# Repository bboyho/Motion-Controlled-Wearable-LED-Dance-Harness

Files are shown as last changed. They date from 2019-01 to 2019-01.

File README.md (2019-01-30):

Motion Controlled Wearable LED Dance Harness
-------------------

This code will be used to control the 12V LED strips attached to a dancer's custom harness. Each harness is controlled using an n-channel MOSFET, an accelerometer, and an Arduino Pro Mini for a performance with Streetside Studio's bboys/bgirls.

<table class="table table-hover table-striped table-bordered">
  <tr align="center">
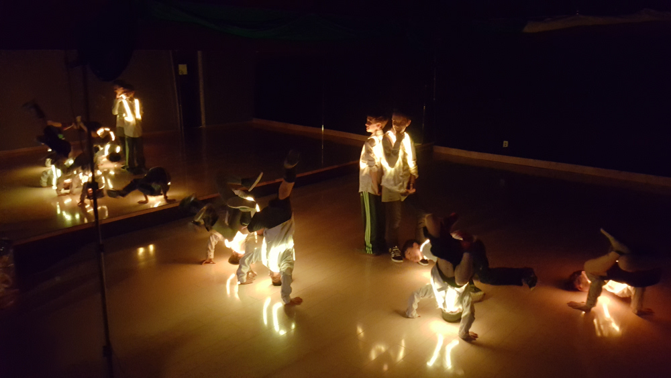
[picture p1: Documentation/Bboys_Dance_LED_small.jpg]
Bboys Freezed
    <td></td>
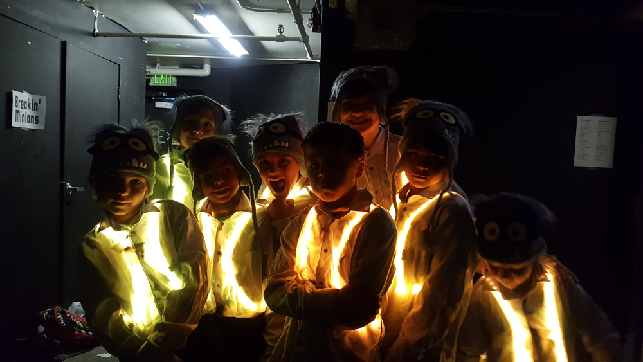
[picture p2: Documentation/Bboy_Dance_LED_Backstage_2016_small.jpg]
Bboys w/ Motion Controlled Wearable LED Dance Harness
    <td></td>
  </tr>
  <tr align="center">
    <td><a href="https://www.instagram.com/p/BExpFgNOczp/">Instagram: bobbybrownrice Demo Image</a></td>
    <td><a href="https://www.instagram.com/p/BFav-Fbucyi/">Instagram: bobbybrownrice Demo Video</a></td>
  </tr>
</table>

For more information about building the harness, check out the tutorials linked below!

Repository Contents
-------------------
* **/Documentation** - Images, Circuit, Fritzing Diagrams
* **/Firmware/Arduino** - Example code 
  * _MinionAccelerometerV2.0_ - Test code for 1 dancer.
  * _MinionAccelerometerV2.1_ - Code calibrated for all 8 dancers.

Documentation
--------------
* Project Tutorial
  * **[Prototype Wearable LED Dance Harness](https://learn.sparkfun.com/tutorials/prototype-wearable-led-dance-harness)** - Project guide to make Mark II of the prototype wearable LED dance harness.
  * **[Motion Controlled Wearable LED Dance Harness](https://learn.sparkfun.com/tutorials/motion-controlled-wearable-led-dance-harness/all)** - Project guide to make Mark III of the wearable LED dance harness. The only difference is that Mark III uses an N-channel MOSFET, accelerometer, and an Arduino Pro Mini to control the colors.
* **[Instagram: bobbybrownrice Demo Video](https://www.instagram.com/p/BExpFgNOczp/)** - Mark III in action.
* **[Instagram: bobbybrownrice Demo Image](https://www.instagram.com/p/BExpFgNOczp/)** - Mark III demo image.

License Information
-------------------

This project is _**open source**_! 

Please review the [LICENSE.md file](https://github.com/bboyho/ledStrap/blob/master/LICENSE.md) for license information. 

Distributed as-is; no warranty is given.

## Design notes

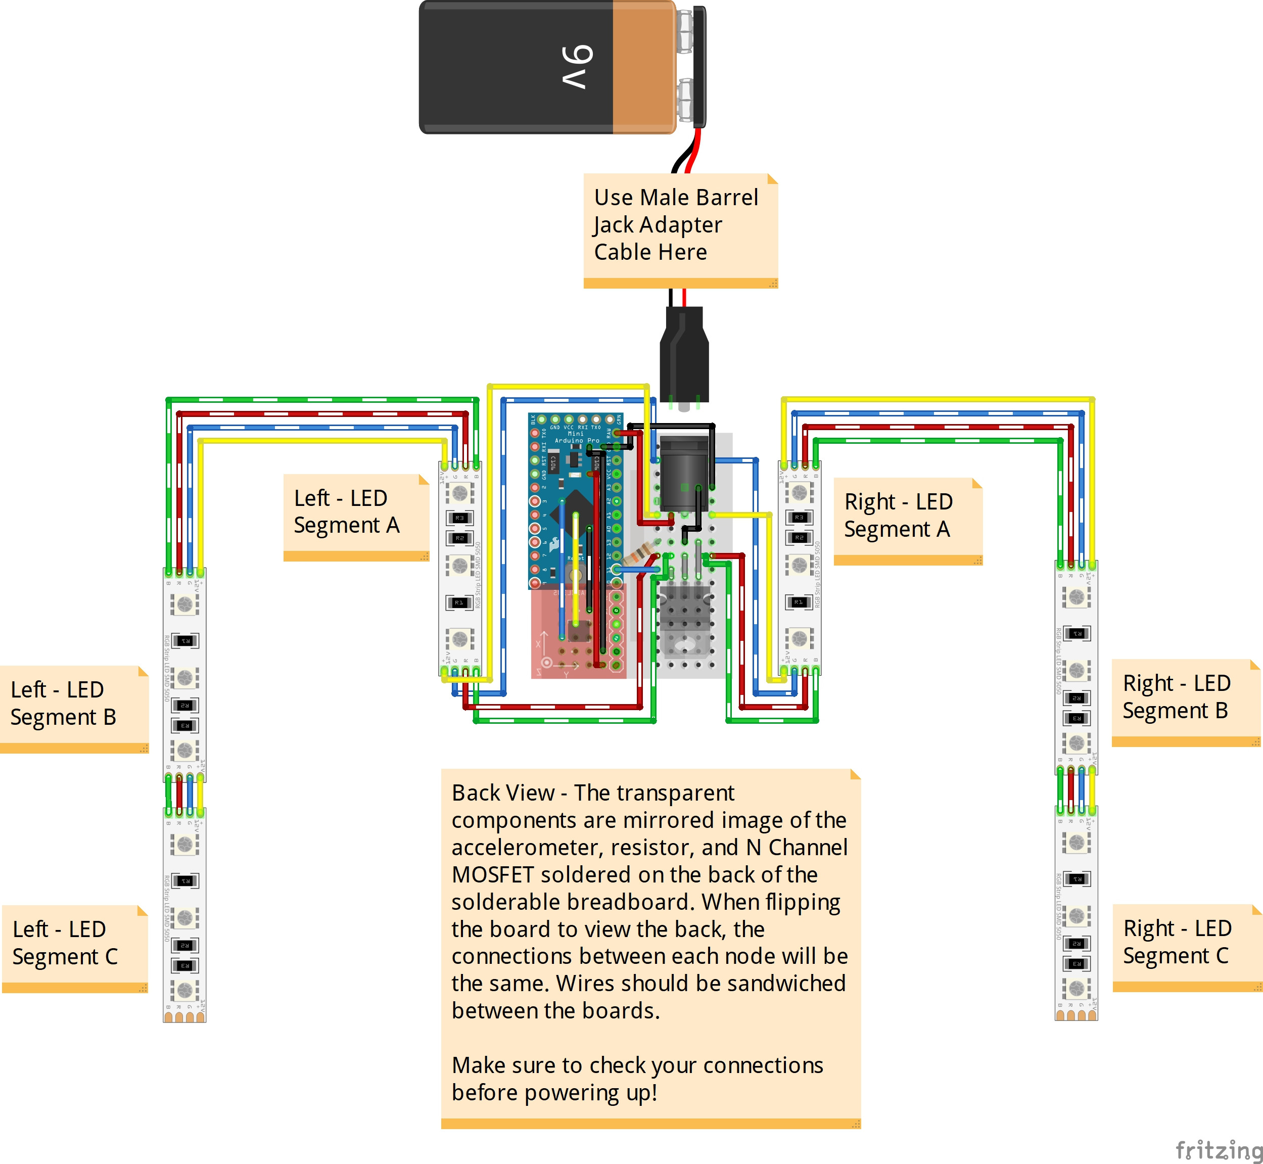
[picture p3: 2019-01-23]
Documentation/SparkFun_MotionControlledWearableLEDDanceHarnessCircuitComplete_Fritzing_Back_View_bb_1.jpg

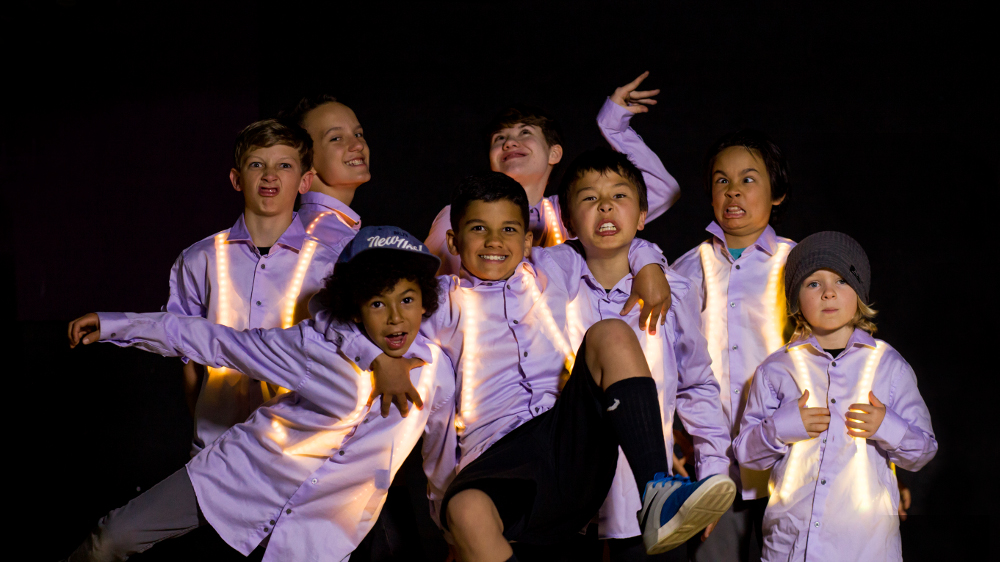
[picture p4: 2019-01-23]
Documentation/BBoys_LED_Harness_Dance_small.jpg

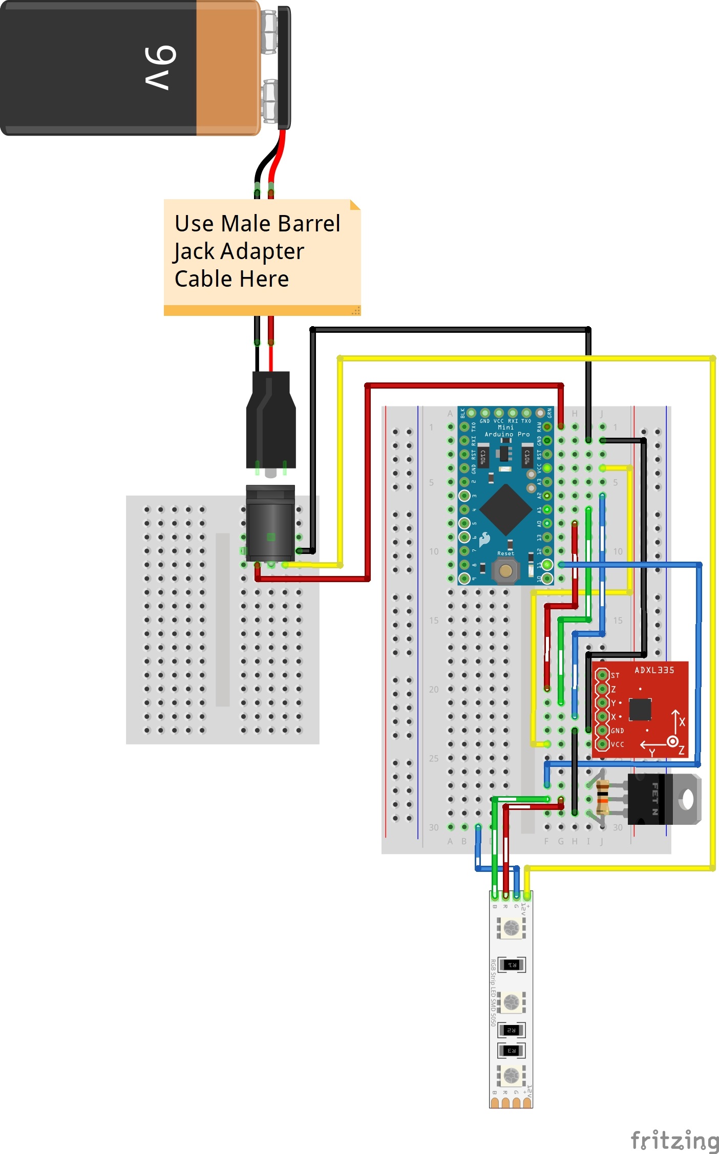
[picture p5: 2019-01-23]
Documentation/SparkFun_MotionControlledWearableLEDDanceHarnessCircuit_Fritzing_bb.jpg

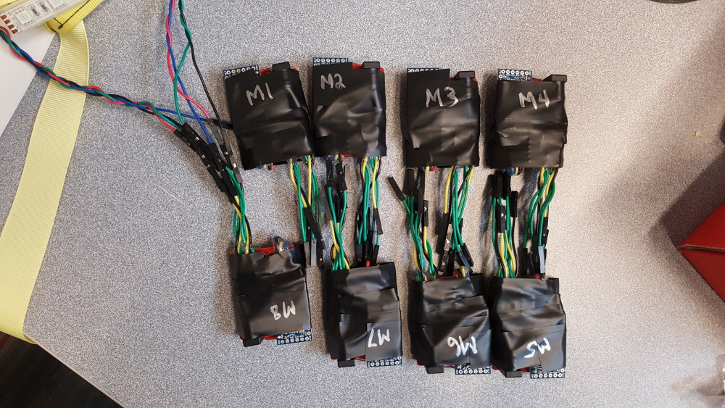
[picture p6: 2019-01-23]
Documentation/Arduino LED Motion Controller_small.jpg

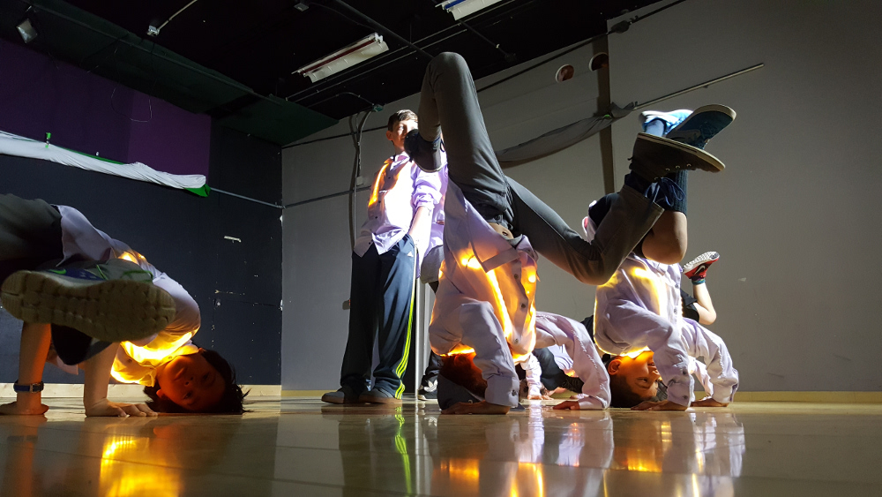
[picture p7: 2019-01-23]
Documentation/Bboys_Dance_LED_Freezes_small.jpg

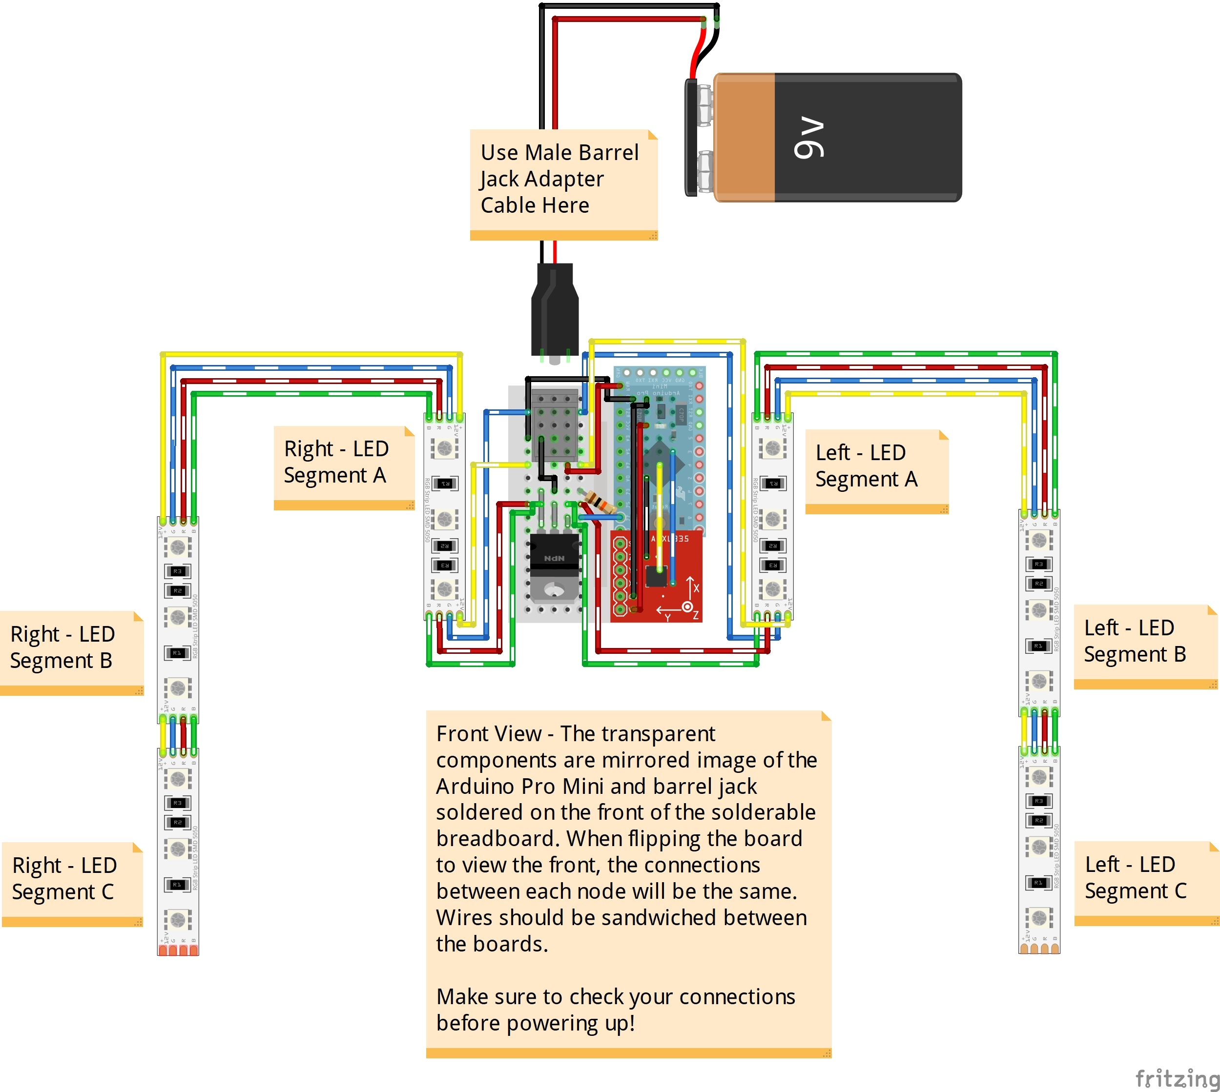
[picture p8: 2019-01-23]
Documentation/SparkFun_MotionControlledWearableLEDDanceHarnessCircuitComplete_Fritzing_Front_View_bb.jpg

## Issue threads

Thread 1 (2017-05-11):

Error in Calibration v2.1

bboyho, 2017-05-11:
There is a problem with the code in the calibration. The condition statement should use a "==" sign.

bboyho, 2019-01-25:
Fixed.

Closed 2019-01-25.

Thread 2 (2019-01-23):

Insert Delay in v2.0

bboyho, 2019-01-23:
Insert delay to slow down reading for manual calibration:

      Serial.println("");
      delay(500);

bboyho, 2019-02-06:
added but commented out the delat in code

Closed 2019-02-06.

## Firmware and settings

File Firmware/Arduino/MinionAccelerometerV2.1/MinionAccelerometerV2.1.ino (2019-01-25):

//MinionAccelerometer.ino
//v2.1
//By: Ho Yun "Bobby" Chan (Worm Tank Crew, Block 1750)
//May 13, 2016
//Sparkfun Electronis Inc.

/*Description: This code will be used to control the 12V LED strips
attached to a dancer's custom strap using an n-channel MOSFET for a
performance with Streetside Studio's bboys/bgirls.

Values calibrated using Earth's gravity when accelerometer at rest.
Depending on what accelerometer is used, change the global variable
calibration_M and calibrationADXL335() for that specific accelerometer.

-------Accelerometer Mode = 1 -------
Features
1.) xAxis
Standing = LED on
Upside down = LED Blinking

2.) yAxis
On the left or right side= LED off

3.) zAxis
On stomach or back = LED fading */

//Code Inspired By:
//bildr ADXL335Example, by Adam Meyer and bildr.org Team
//[ http://bildr.org/2011/04/sensing-orientation-with-the-adxl335-arduino/ ]
//[ http://bildr.org/2012/03/rfp30n06le-arduino/ ]
//Arduino Fade Example, by David A. Mellis and Tom Igoe
//[ http://www.arduino.cc/en/Tutorial/Fading ]

//set analog read pins
const int xPin = 2;//x=A2
const int yPin = 1;//y=A1
const int zPin = 0;//z=A0

//read the analog values from the accelerometer
int xRead = analogRead(xPin);
int yRead = analogRead(yPin);
int zRead = analogRead(zPin);

//Calibration
int calibration_M = 8; //this is used to calibrate the different accelerometers, change depending on what you are calibrating
//default calibration values for quick test of the adapter board
int xUp = 605;
int xDown = 411;
int yUp = 607;
int yDown = 409;
int zUp = 610;
int zDown = 425;

//delay for blinking
int t = 50;

//LED
int ledStatus = 13; //on board LED for testing
int ledFade = 11; //pin to control N-channel mosfet and LEDs.

void setup() {
  //for testing, init serial monitor
  Serial.begin(9600);
  Serial.println("Start Reading Accelerometer");

  //function for calibrating accelerometers
  calibrationADXL335();

  // initialize the digital pin as an output.
  pinMode(ledStatus, OUTPUT);
  for (int i = 0; i < 3; i++) {
    //blink 3 times
    digitalWrite(ledStatus, HIGH);  // turn the LED on (HIGH is the voltage level)
    delay(20);               // wait for a second
    digitalWrite(ledStatus, LOW);   // turn the LED off by making the voltage LOW
    delay(20);               // wait for a second
  }

  //initialize pin as an output
  pinMode(ledFade, OUTPUT);
  digitalWrite(ledFade, HIGH);   // turn the LED on (HIGH is the voltage level)
}

void loop() {

  //Read accelerometer axes using through the ADC
  //Note: Check description at top for results based on Accelerometer Mode's Features
  xRead = analogRead(xPin);
  Serial.print("Analog xPin (A0) = ");
  Serial.print(xRead);
  yRead = analogRead(yPin);
  Serial.print("     Analog yPin (A1) = ");
  Serial.print(yRead);
  zRead = analogRead(zPin);
  Serial.print("     Analog zPin (A2) = ");
  Serial.println(zRead);

  //-------Accelerometer Mode = 1 -------
  //X-X-X-X-X-X-X | READ xAxis | X-X-X-X-X-X-X
  //LEDs ON
  if (xRead > xUp) {
    //Note: When standing (xAxis pointing up or slightly tilted), it's ~600-604 at REST
    //           ...Other values are outside of this boundary, therefore it will not affect this case
    digitalWrite(ledFade, HIGH);   // turn the LED on (HIGH is the voltage level)
  }
  //LEDs Blinking
  else if (xRead < xDown) {
    //Note: When upside down (xAxis pointing down or slightly tilted), it's ~399-411 at REST
    //           ...Other values are outside of this boundary, therefore it will not affect this case
    digitalWrite(ledFade, HIGH);   // turn the LED on (HIGH is the voltage level)
    delay(t);               // wait for a a few milliseconds
    digitalWrite(ledFade, LOW);    // turn the LED off by making the voltage LOW
    delay(t);               // wait for a a few milliseconds
  }
  //xxxxxxxxxxxxxxxxxxxxxxxxxxxxxxxxxxxxxxxx

  //Y-Y-Y-Y-Y-Y-Y | Read yAxis | Y-Y-Y-Y-Y-Y-Y
  //LEDs OFF
  else if (yRead > yUp || yRead < yDown ) {
    //Note: When on left side (yAxis), it's ~607-612 at REST
    //Note: When on right side (yAxis), it's ~395-409 at REST
    //           ...Other values are outside of this boundary, therefore it will not affect this case
    digitalWrite(ledFade, LOW);    // turn the LED off by making the voltage LOW
  }
  //yyyyyyyyyyyyyyyyyyyyyyyyyyyyyyyyyyyyyyyy

  //Z-Z-Z-Z-Z-Z-Z | read xAxis | Z-Z-Z-Z-Z-Z-Z
  //
  else if (zRead > zUp || zRead < zDown) {
    //fadeIn example from Arduino Fade Example Code

    //Note: When on back (zAxis pointing up or tilted), it's ~ 610-618 at REST
    //Note: When on stomach (zAxis pointing down or tilted), it's ~ 410-425 at REST
    //           ...Other values are outside of this boundary, therefore it will not affect this case
    for (int fadeValue = 0 ; fadeValue <= 255; fadeValue += 5) {
      // sets the value (range from 0 to 255):
      analogWrite(ledFade, fadeValue);
      // wait for 30 milliseconds to see the dimming effect
      delay(10);
    }
    //fadeOut
    // fade out from max to min in increments of 5 points:
    for (int fadeValue = 255 ; fadeValue >= 0; fadeValue -= 5) {
      // sets the value (range from 0 to 255):
      analogWrite(ledFade, fadeValue);
      // wait for 30 milliseconds to see the dimming effect
      delay(10);
    }
  }
  //zzzzzzzzzzzzzzzzzzzzzzzzzzzzzzzzzzzzzzzzzzzz

}

void calibrationADXL335() {
  //function to calibrate ADXL335 accelerometers due to manufacturing tolerances
  //read the values sent through the Arduino serial monitor to determine the values
  //when calibrating. adjust the values accordingly. the values in the brackets are
  //the min/max values used for the condition statements
  if (calibration_M == 1) {
    xUp = 540;      //xRead > xUp, ...~ [550]-580 at REST
    xDown = 488;    //xRead < xDown, it's ~437-[488] at REST
    yUp = 544;      //yRead > yUp, it's ~[544]-580 at REST
    yDown = 480;    //yRead < yDown, it's ~445-[480] at REST
    zUp = 608;      //zRead > zUp, it's ~[608]-642 at REST
    zDown = 435;    //zRead < zDown, it's ~414-[435] at REST
  }
  else  if (calibration_M == 2) {
    xUp = 570;      //xRead > xUp, ...~ [570]-607 at REST
    xDown = 436;    //xRead < xDown, it's ~405-[436] at REST
    yUp = 610;      //yRead > yUp, it's ~[610]-610 at REST
    yDown = 430;    //yRead < yDown, it's ~407-[430] at REST
    zUp = 613;      //zRead > zUp, it's ~[592]-619 at REST
    zDown = 440;    //zRead < zDown, it's ~410-[440] at REST
  }
  else if (calibration_M == 3) {
    xUp = 590;      //xRead > xUp, ...~ [590]-607 at REST
    xDown = 436;    //xRead < xDown, it's ~404-[436] at REST
    yUp = 601;      //yRead > yUp, it's ~[601]-610 at REST
    yDown = 419;    //yRead < yDown, it's ~405-[418] at REST
    zUp = 592;      //zRead > zUp, it's ~[592]-619 at REST
    zDown = 430;    //zRead < zDown, it's ~410-[430] at REST
  }
  else if (calibration_M == 4) {
    xUp = 585;      //xRead > xUp, ...~ [585]-604 at REST
    xDown = 424;    //xRead < xDown, it's ~407-[424] at REST
    yUp = 598;      //yRead > yUp, it's ~[598]-607 at REST
    yDown = 420;    //yRead < yDown, it's ~405-[420] at REST
    zUp = 615;      //zRead > zUp, it's ~[615]-622 at REST
    zDown = 441;    //zRead < zDown, it's ~421-[441] at REST
  }

  else if (calibration_M == 5) {
    xUp = 590;      //xRead > xUp, ...~ [590]-607 at REST
    xDown = 437;    //xRead < xDown, it's ~408-[437] at REST
    yUp = 598;      //yRead > yUp, it's ~[598]-610 at REST
    yDown = 412;    //yRead < yDown, it's ~407-[412] at REST
    zUp = 600;      //zRead > zUp, it's ~[600]-620 at REST
    zDown = 431;    //zRead < zDown, it's ~421-[431] at REST
  }
  else if (calibration_M == 6) {
    xUp = 580;      //xRead > xUp, ...~ [580]-610 at REST
    xDown = 413;    //xRead < xDown, it's ~404-[413] at REST
    yUp = 601;      //yRead > yUp, it's ~[595]-605 at REST
    yDown = 411;    //yRead < yDown, it's ~405-[411] at REST
    zUp = 607;      //zRead > zUp, it's ~[607]-625 at REST
    zDown = 430;    //zRead < zDown, it's ~418-[430] at REST
  }
  else if (calibration_M == 7) {
    xUp = 585;      //xRead > xUp, ...~ [585]-607 at REST
    xDown = 429;    //xRead < xDown, it's ~407-[429] at REST
    yUp = 603;      //yRead > yUp, it's ~[603]-611 at REST
    yDown = 419;    //yRead < yDown, it's ~407-[420] at REST
    zUp = 605;      //zRead > zUp, it's ~[605]-618 at REST
    zDown = 434;    //zRead < zDown, it's ~411-[434] at REST
  }
  else if (calibration_M == 8) {
    xUp = 585;      //xRead > xUp, ...~ [585]-67 at REST
    xDown = 436;    //xRead < xDown, it's ~405-[436] at REST
    yUp = 593;      //yRead > yUp, it's ~[593]-615 at REST
    yDown = 420;    //yRead < yDown, it's ~407-[420] at REST
    zUp = 595;      //zRead > zUp, it's ~[595]-614 at REST
    zDown = 440;    //zRead < zDown, it's ~411-[440] at REST
  }
  else {

    xUp = 585;      //xRead > xUp, ...~ [585]-607 at REST
    xDown = 436;    //xRead < xDown, it's ~405-[436] at REST
    yUp = 601;      //yRead > yUp, it's ~[601]-615 at REST
    yDown = 419;    //yRead < yDown, it's ~404-[419] at REST
    zUp = 616;      //zRead > zUp, it's ~[616]-642 at REST
    zDown = 440;    //zRead < zDown, it's ~410-[440] at REST
  }

  //
  /*
   * //calibration with tech support ADXL335.
    //default calibration_M = 0
    //default calibration for quick test of the adapter board
    xUp = 605;    //xRead > xUp, it's~[600]-604 at REST
    xDown = 411;  //xRead < xDown, it's ~399-[411] at REST
    yUp = 607;    //yRead > yUp, it's ~[607]-612 at REST
    yDown = 409;  //yRead < yDown, it's ~395-[409] at REST
    zUp = 610;    //zRead > zUp, it's ~[610]-618 at REST
    zDown = 425;  //zRead < zDown, it's ~ 410-[425] at REST
    */

}

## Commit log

2016-04-12 Adding Example Code
    Example Code to control LEDs calibrated with Earth's gravity.
2016-04-20 Update and rename Arduino/MinionAccelerometer to Arduino/MinionAccelerometerV2.0/MinionAccelerometerV2.0.ino
2016-04-20 Calibration
    adding section for calibration.
2016-04-20 Rename Arduino/MinionAccelerometerv2.1.ino to Arduino/MinionAccelerometerv2.1./MinionAccelerometerv2.1.ino
    Place in new directory
2016-04-30 Calibration and Fixed Buggy If Statement
    -Commented out Tech Support's ADXL335's Accelerometer
    -Changed If Statements to If Else. Was buggy when just using if statements.
    -Calibrated M1-M7.
    -M1's accelerometer has the same x and y values for some strange reason. Damaged?
    -Check M5
    -Need to calibrate M8
    [MinionAccelerometerV2.1.ino]
2016-04-30 Update MinionAccelerometerV2.1.ino
    -Removed Println statement when viewing x and y values from M1
    -Removed some comments that were copied from Tech Support's ADXL values.
2016-05-13 Update MinionAccelerometerV2.1.ino
    Adding M8 calibration.
2016-05-13 Update MinionAccelerometerV2.1.ino
    There was a short between the X and Y pins of the accelerometer from reworking the solderable breadboard. Added M1's calibration.
    [MinionAccelerometerV2.1.ino]
2019-01-23 Updates
    -Add Fritzing Diagrams
    -Add JPG Images of Circuits
    -Add Images for Documentation
    -Update Pin in v2.0
    -Adjust File Path for Example Code
    [SparkFun_MotionControlledWearableLEDDanceHarnessCircuitComplete_Fritzing_Back_View.fzz, SparkFun_MotionControlledWearableLEDDanceHarnessCircuitComplete_Fritzin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]
